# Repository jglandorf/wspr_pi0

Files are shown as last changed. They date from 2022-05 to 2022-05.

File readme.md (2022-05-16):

## RPi Zero W WSPR Amplifier

 - A 100mW+ HF transmit amplifier daughterboard for the Raspberry Pi Zero W
 - Direct connection of dipole antenna
 - Select one of two HF band low-pass filters via jumper.  30M LPF built-in; 2nd LPF user-supplied.
 - OLED direct plug-in
 - Part of the ARROW Communication Association (w8rp.org) Build Sessions, Aug 2019
 - See docs/wspr_pi0_assembly.pdf
 
 73 de Joe, AC8ES

https://github.com/jglandorf/wspr_pi0.git
https://github.com/jglandorf/wspr_pi0.git/docs
https://github.com/jglandorf/wspr_pi0.git/RPi0_usdCardImage

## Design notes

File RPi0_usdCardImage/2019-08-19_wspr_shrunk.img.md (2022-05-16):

Download the Raspberry Pi Zero W image from:
 https://drive.google.com/file/d/1zh98SfC52pd-oitz9gwardmH-K3YmRiI/view?usp=sharing
 2019-08-19_wspr_shrunk.img.xz
Note that the Raspberry Pi Imager, https://www.raspberrypi.com/software/, can flash a uSD Card directly from coompressed .xy images.

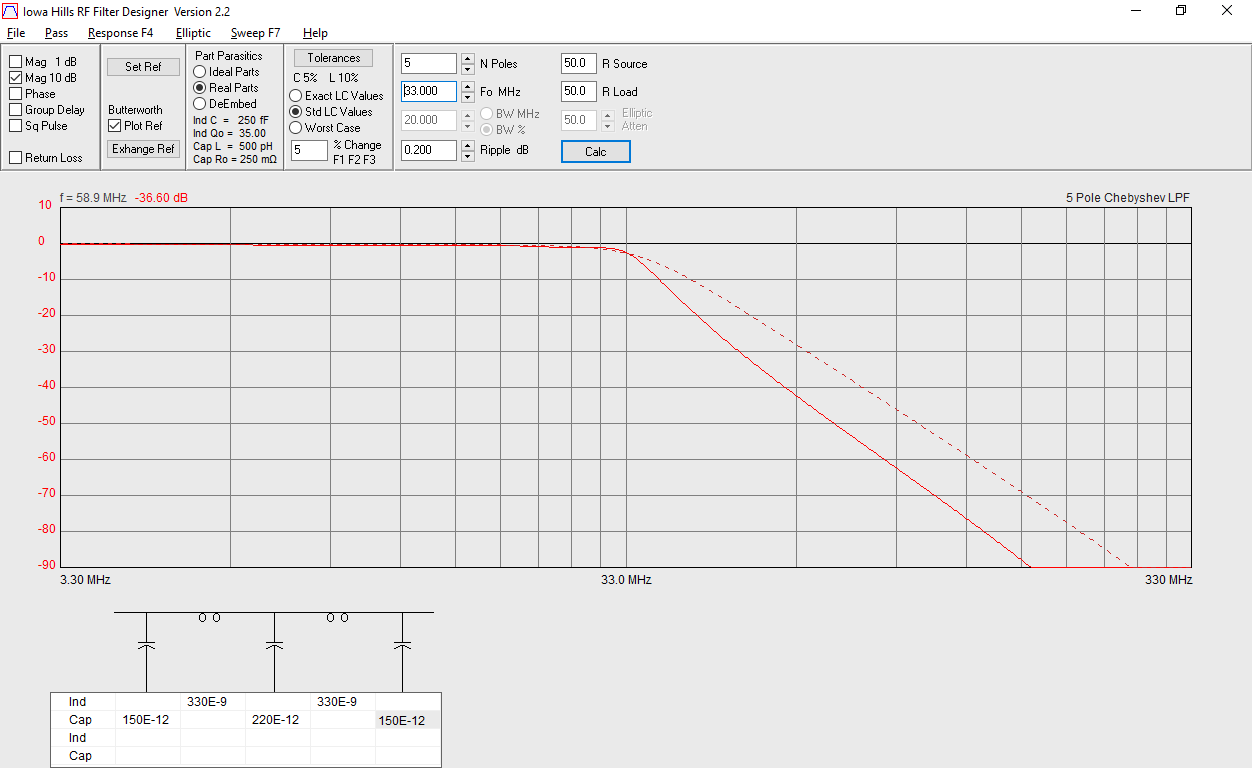
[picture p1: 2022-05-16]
design_notes/lpf_33MHz.png

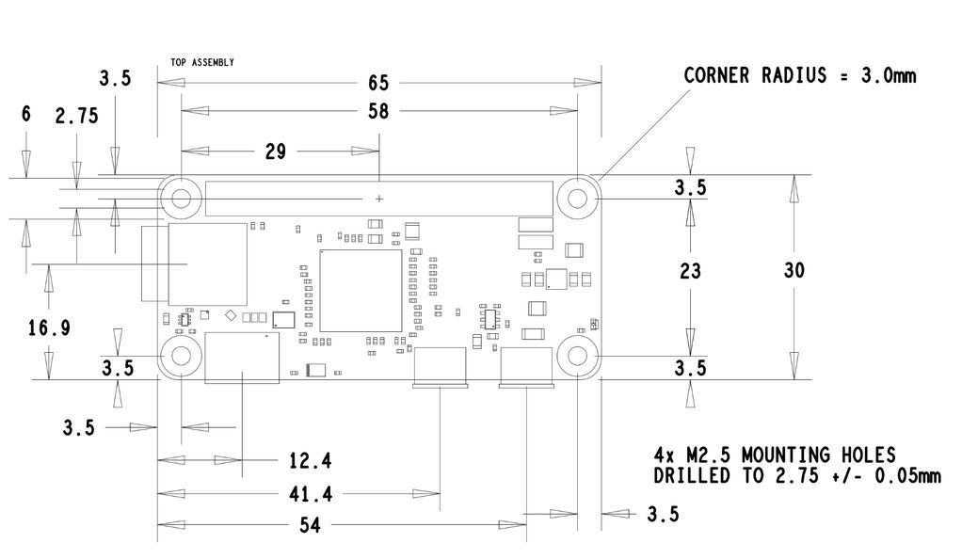
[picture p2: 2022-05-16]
datasheets/Raspberry-Pi-Zero-Dimensions-Footprint.jpg

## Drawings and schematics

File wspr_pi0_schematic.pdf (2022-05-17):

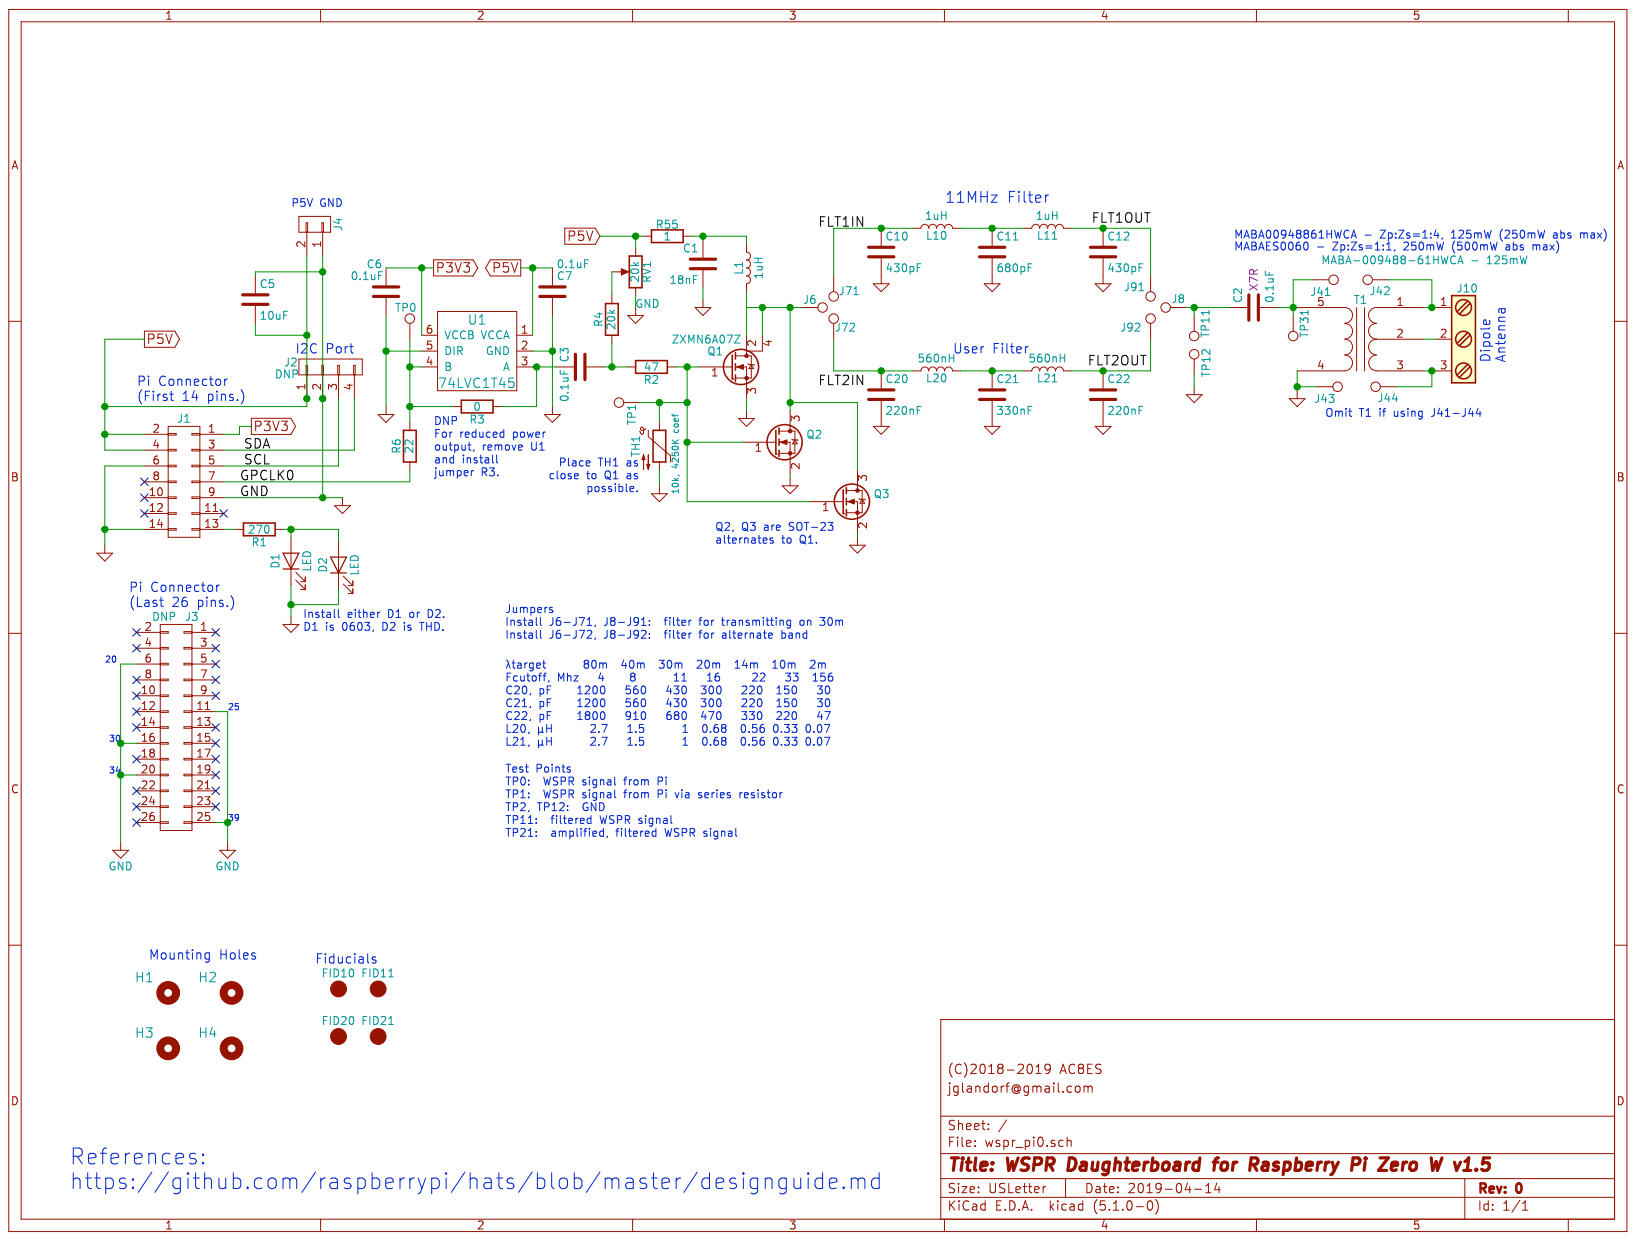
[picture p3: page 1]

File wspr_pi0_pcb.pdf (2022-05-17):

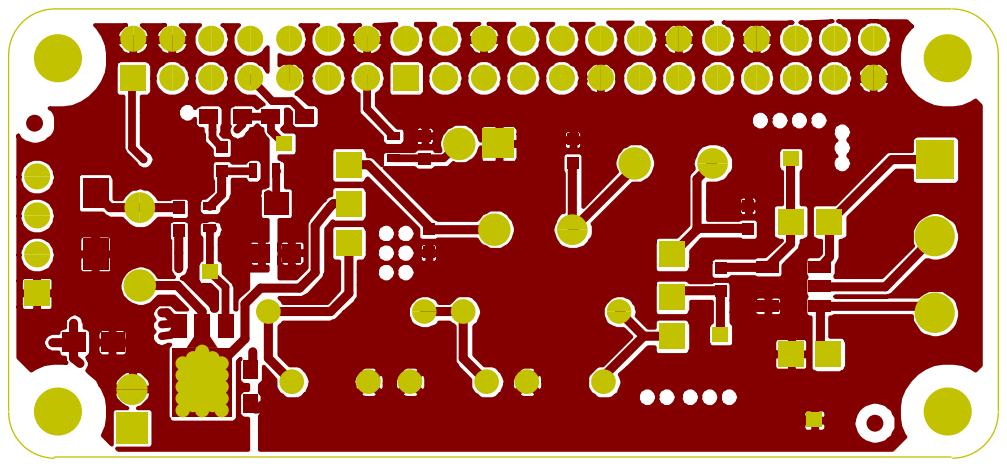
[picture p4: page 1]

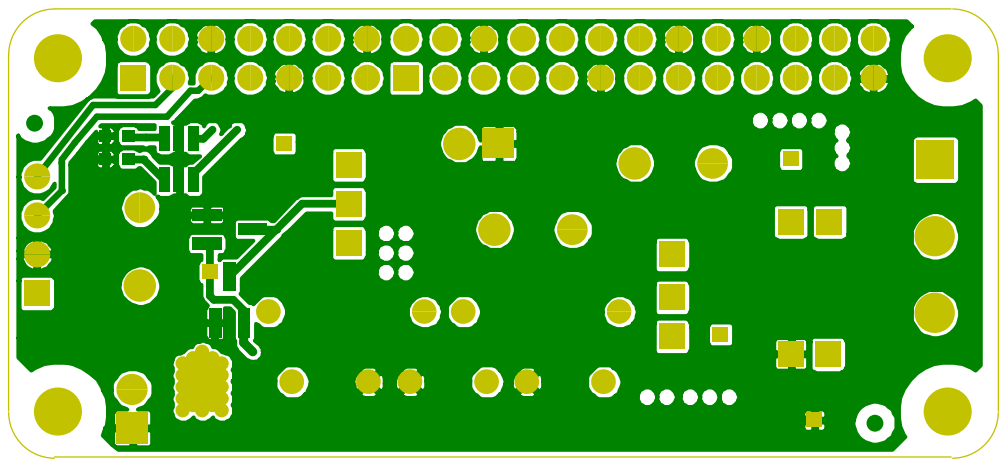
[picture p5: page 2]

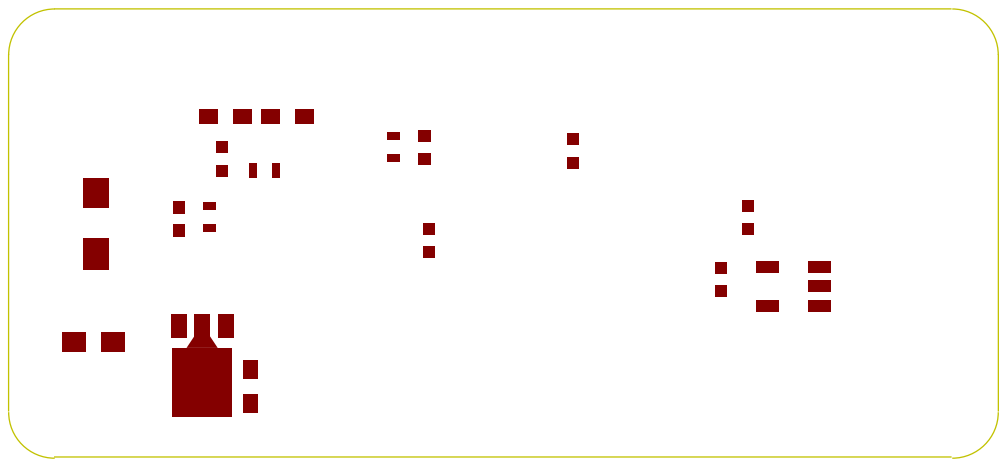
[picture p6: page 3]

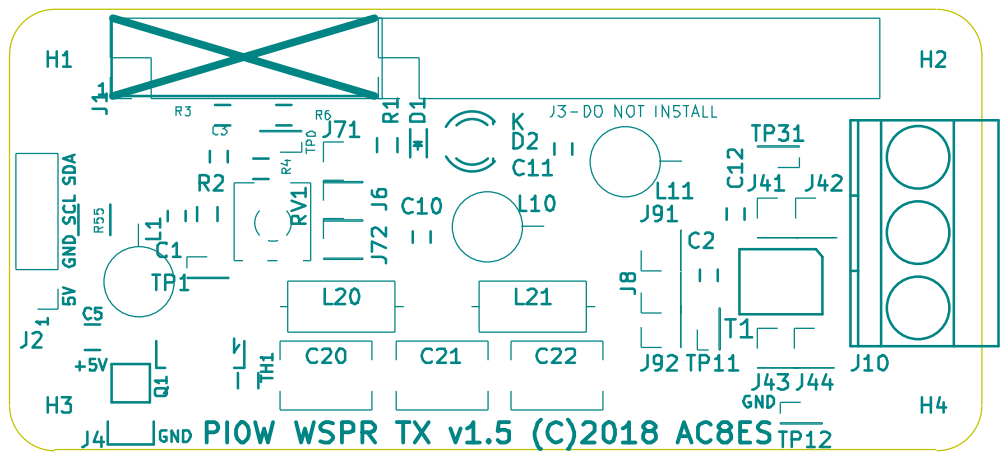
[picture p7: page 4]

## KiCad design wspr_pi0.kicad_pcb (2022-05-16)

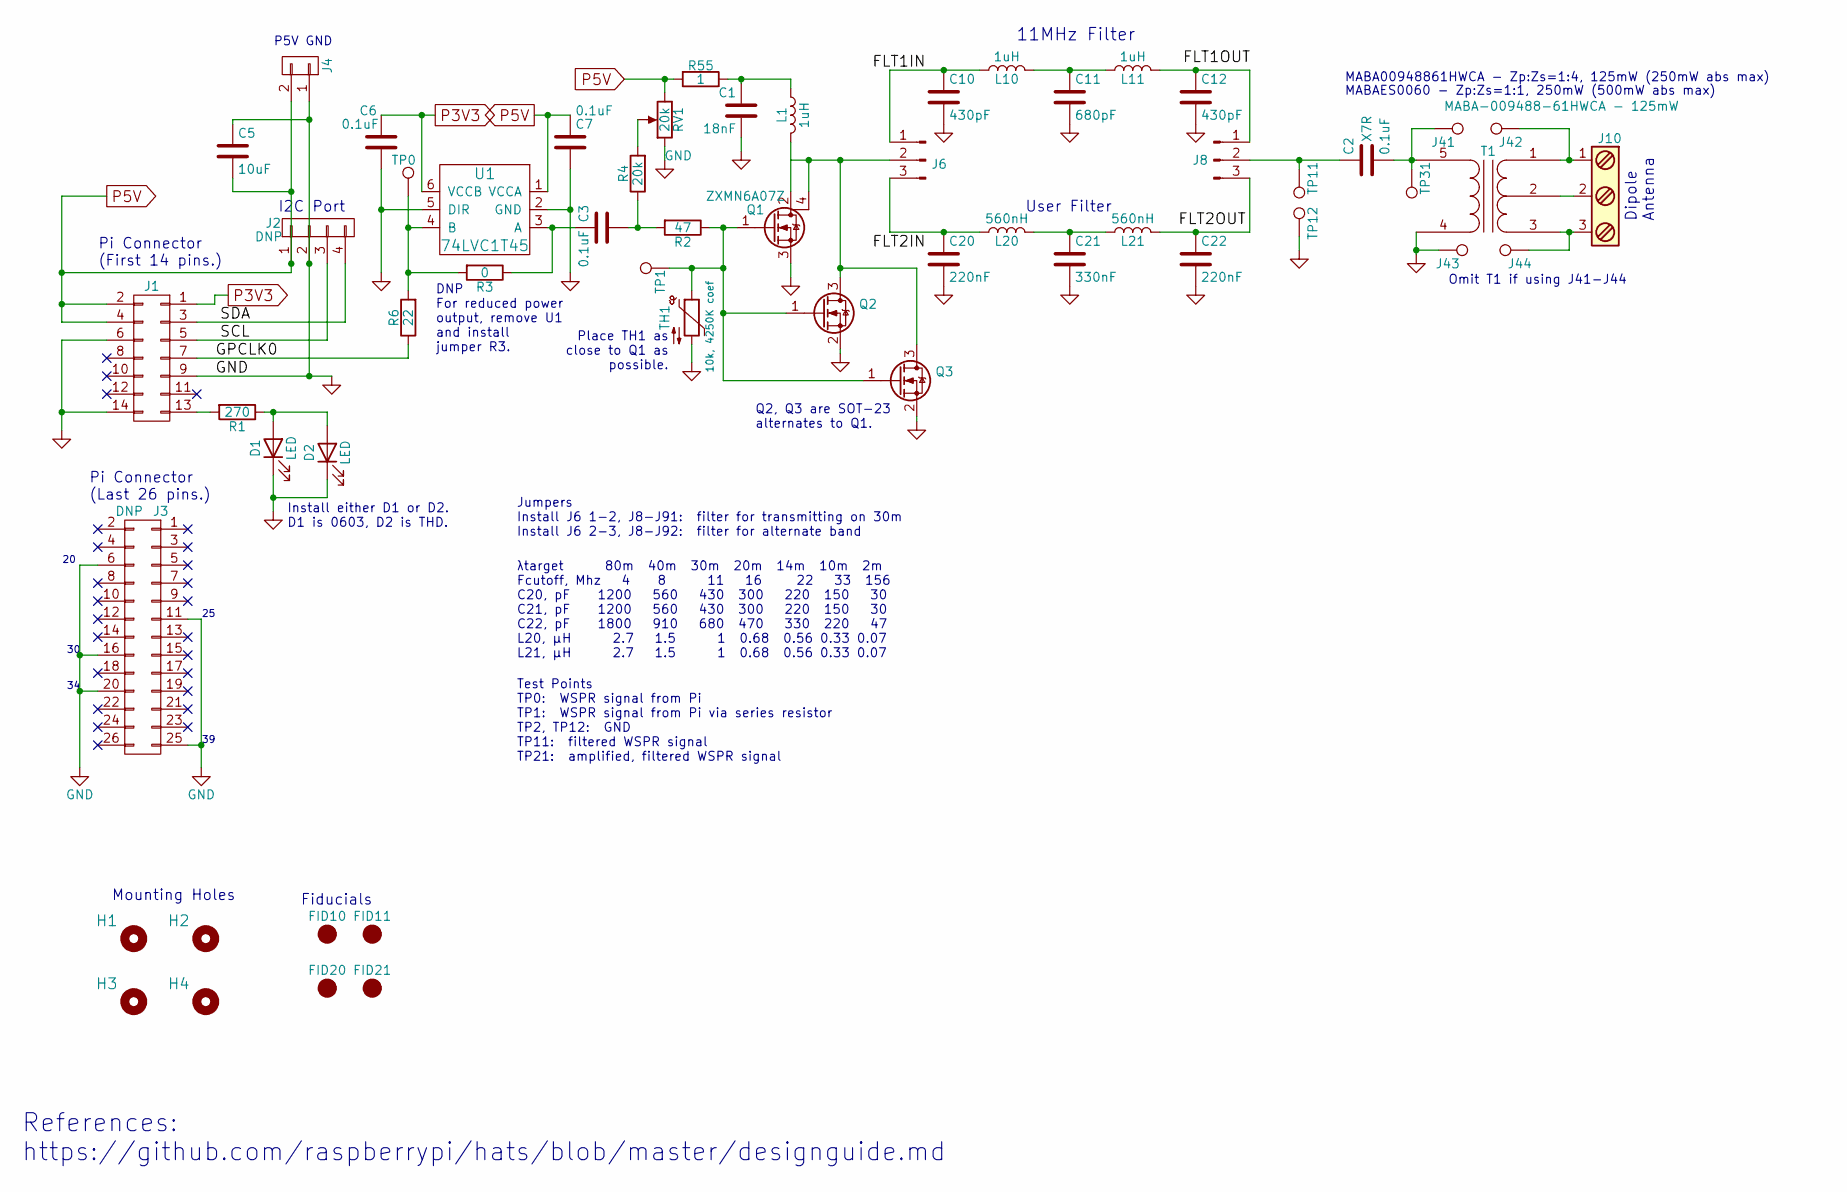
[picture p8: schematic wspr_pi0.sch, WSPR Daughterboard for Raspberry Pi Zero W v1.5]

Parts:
C1: 18nF; C_0603
C2, C3, C6, C7: 0.1uF; C_0603
C5: 10uF; C_0805_HandSoldering
C10, C12: 430pF; C_0603
C11: 680pF; C_0603
C20, C22: 220nF; C_Disc_D6.0mm_W4.4mm_P5.00mm; MPN FG28X7R1H224KRT06
C21: 330nF; C_Disc_D6.0mm_W4.4mm_P5.00mm; MPN FG28X7R1H334KRT06
D1: LED; LED_0603; MPN 19-217/R6C-AL1M2VY/3T
D2: LED; LED-3MM; MPN WP710A10LSRD
FID10, FID11: CIRCLE1mmDia; Fiducial_1mm_Dia_2.54mm_Outer_CopperTop; MPN DNP
FID20, FID21: CIRCLE1mmDia; Fiducial_1mm_Dia_2.54mm_Outer_CopperBottom; MPN DNP
H1, H2: 3mm_Mounting_Hole; NPTH_3mm_ID; MPN DNP
H3, H4: 3mm_Mounting_Hole_Unlocked; NPTH_3mm_ID_Unlocked; MPN DNP
J1: CONN_02X07; Pin_Header_Straight_2x07_Pitch2.54mm; MPN SFH11-PBPC-D07-ST-BK
J2: DNP; Pin_Header_Straight_1x04_Pitch2.54mm
J3: DNP; Pin_Header_Straight_2x13_Pitch2.54mm; MPN DNP
J4: CONN_01X02; Pin_Header_Straight_1x02
J6, J8: Conn_01x03_Male; PinHeader_1x03_P2.54mm_Vertical
J10: Screw_Terminal_1x03; TerminalBlock_Pheonix_MKDS1.5-3pol; MPN 0398800303
J41, J42, J43, J44: TEST_1P; Socket_Strip_Straight_1x01_Pitch2.54mm; MPN DNP
L1, L10, L11: 1uH; L_Axial_L11.0mm_D4.5mm_P5.08mm_Vertical_Fastron_MECC; MPN B78108S1102K000
L20, L21: 560nH; L_Axial_L7.0mm_D3.3mm_P10.16mm_Horizontal_Fastron_MICC; MPN 78FR56K-RC
Q1: ZXMN6A07Z; SOT89-3_MOSFET; MPN ZXMN6A07ZCT
Q2, Q3: DNP; SOT-23_Handsoldering; MPN IRLML2030TRPbF
R1: 270; R_0603; MPN RC0603JR-07270RL
R2: 47; R_0603; MPN RC0603JR-0747RL
R3: 0; R_0603_HandSoldering; MPN ERJ-3GEY0R00V
R4: 20k; R_0603
R6: 22; R_0603_HandSoldering
R55: 1; R_1206_HandSoldering
RV1: 20k; Potentiometer_Bourns_TC33X
T1: MABA-009488-61HWCA - 125mW; SO-BALUN-5_SMD; MPN MABA-009488-61HWCA
TH1: 10k, 4250K coef; R_0603_HandSoldering; MPN ERT-J1VR103J
TP0, TP1, TP11, TP12, TP31: TEST_1P; Pin_Header_Straight_1x01_Pitch1.27mm; MPN DNP
U1: 74LVC1T45; SOT-23-6_Handsoldering

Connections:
/GPCLK0: J1.7, R6.1
/SCL: J1.5, J2.3
/SDA: J1.3, J2.4
GND: C1.2, C5.1, C6.2, C7.2, C10.2, C11.2, C12.2, C20.2, C21.2, C22.2, D1.1 (K), D2.1 (K), J1.6, J1.9, J1.14, J2.2, J3.6, J3.11, J3.16, J3.20, J3.25, J4.1, J43.1, Q1.3 (S), Q2.2 (S), Q3.2 (S), RV1.1, T1.4 (PR1), TH1.2, TP12.1, U1.2 (GND), U1.5 (DIR)
unnamed: C1.1, L1.2, R55.1
unnamed: C2.1, J8.2, TP11.1
unnamed: C2.2, J41.1, T1.5 (PR2), TP31.1
unnamed: C3.1, R3.1, U1.3 (A)
unnamed: C3.2, R2.2, R4.1
unnamed: C10.1, J6.1, L10.1
unnamed: C11.1, L10.2, L11.1
unnamed: C12.1, J8.1, L11.2
unnamed: C20.1, J6.3, L20.1
unnamed: C21.1, L20.2, L21.1
unnamed: C22.1, J8.3, L21.2
unnamed: D1.2 (A), D2.2 (A), R1.1
unnamed: J1.13, R1.2
unnamed: J6.2, Q1.4 (D), Q2.3 (D), Q3.3 (D)
unnamed: J10.1, J42.1, T1.1 (S1)
unnamed: J10.2, T1.2 (SM)
unnamed: J10.3, J44.1, T1.3 (S2)
unnamed: L1.1, Q1.2 (D)
unnamed: Q1.1 (G), Q2.1 (G), Q3.1 (G), R2.1, TH1.1, TP1.1
unnamed: R3.2, R6.2, TP0.1, U1.4 (B)
unnamed: R4.2, RV1.2
P3V3: C6.1, J1.1, U1.6 (VCCB)
P5V: C5.2, C7.1, J1.2, J1.4, J2.1, J4.2, R55.2, RV1.3, U1.1 (VCCA)

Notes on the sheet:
Mounting Holes
Pi Connector (First 14 pins.)
References: https://github.com/raspberrypi/hats/blob/master/designguide.md
11MHz Filter
User Filter
I2C Port
Dipole Antenna
Pi Connector (Last 26 pins.)
Fiducials
MABA00948861HWCA - Zp:Zs=1:4, 125mW (250mW abs max)
MABAES0060 - Zp:Zs=1:1, 250mW (500mW abs max)
Jumpers Install J6 1-2, J8-J91: filter for transmitting on 30m Install J6 2-3, J8-J92: filter for alternate band
Test Points TP0: WSPR signal from Pi TP1: WSPR signal from Pi via series resistor TP2, TP12: GND TP11: filtered WSPR signal TP21: amplified, filtered WSPR signal
λtarget 80m 40m 30m 20m 14m 10m 2m Fcutoff, Mhz 4 8 11 16 22 33 156 C20, pF 1200 560 430 300 220 150 30 C21, pF 1200 560 430 300 220 150 30 C22, pF 1800 910 680 470 330 220 47 L20, μH 2.7 1.5 1 0.68 0.56 0.33 0.07 L21, μH 2.7 1.5 1 0.68 0.56 0.33 0.07
Omit T1 if using J41-J44
Install either D1 or D2. D1 is 0603, D2 is THD.
P5V GND
Place TH1 as close to Q1 as possible.
Q2, Q3 are SOT-23 alternates to Q1.
DNP For reduced power output, remove U1 and install jumper R3.

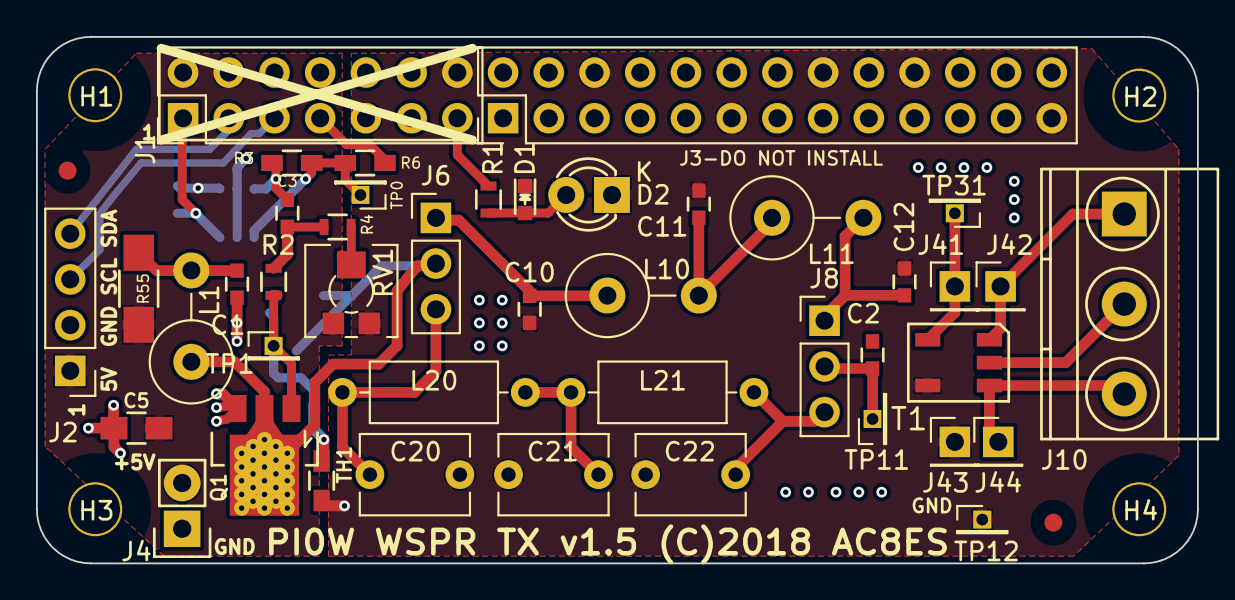
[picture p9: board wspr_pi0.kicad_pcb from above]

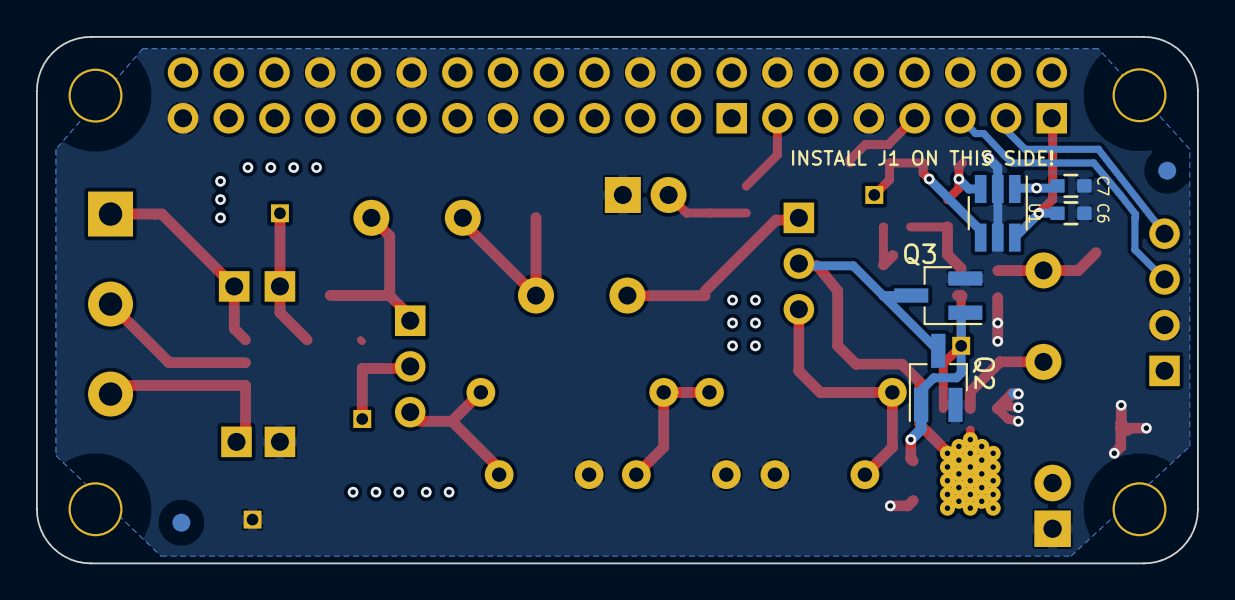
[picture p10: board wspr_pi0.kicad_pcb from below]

Board: 2 copper layers, 64.5 x 29.2 mm, 56 parts (5 on the bottom side), 27 nets.

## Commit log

2022-05-16 Initial commit.
    [wspr_pi0-2019-03-19-21-04-01.sch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]
2022-05-17 Add pdf versions of schematic and layout.

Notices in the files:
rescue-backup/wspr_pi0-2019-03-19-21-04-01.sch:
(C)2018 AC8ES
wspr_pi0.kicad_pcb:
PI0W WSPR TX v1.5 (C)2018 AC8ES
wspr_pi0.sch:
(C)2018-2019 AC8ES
